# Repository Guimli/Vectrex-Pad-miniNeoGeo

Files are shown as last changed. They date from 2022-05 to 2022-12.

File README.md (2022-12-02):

# Vectrex Pad miniNeoGeo

Allows you to convert a mini NeoGeo controller into a Vectrex controller.

This PCB reuses the analog pad of the mini NeoGeo controller. You will have to unsolder it from the original PCB.
There are two models of the NeoGeo mini controller. One contains classic directional switches (you can hear the clicks when using the directional controller). The other one uses an analogue pad. Make sure you have the right model of controller (the one with the analogue pad) before you start making this Vectrex mod.

!!! Please note that the PCB must be 1.2mm thick !!!

!!! Another warning: It is essential to cut the pins of the two auto-fire switches SW5 and SW6 (OS203011MS1QP1) at the level of the PCB BEFORE soldering. This is because the plastic of the lower part of the joystick has two rings that press on this area. Over soldering in this area could block the auto-fire buttons and deform the plastic at the back.

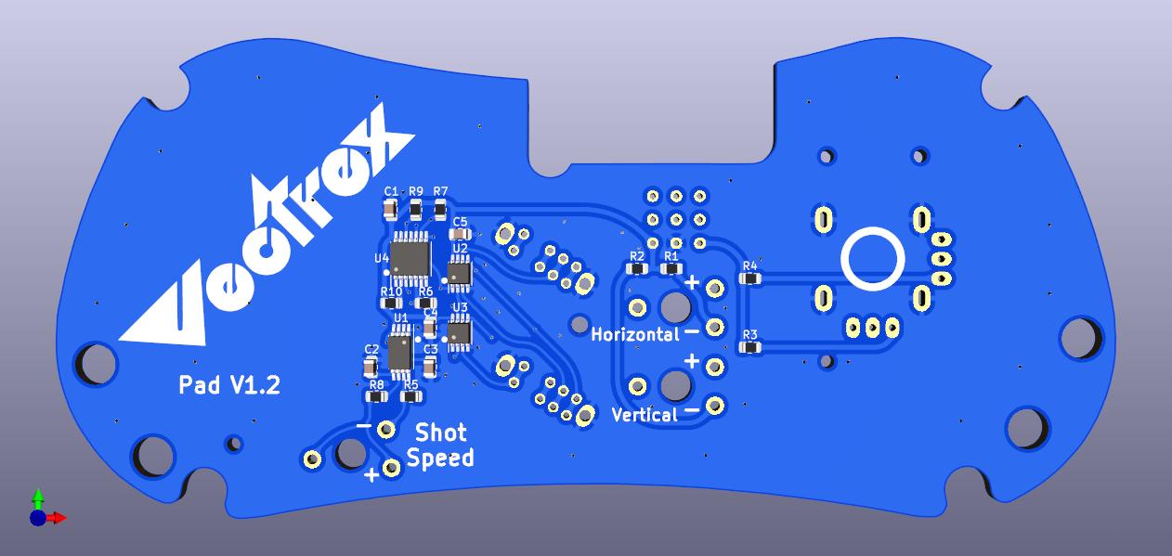
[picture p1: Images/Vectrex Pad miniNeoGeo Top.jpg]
PCB Top


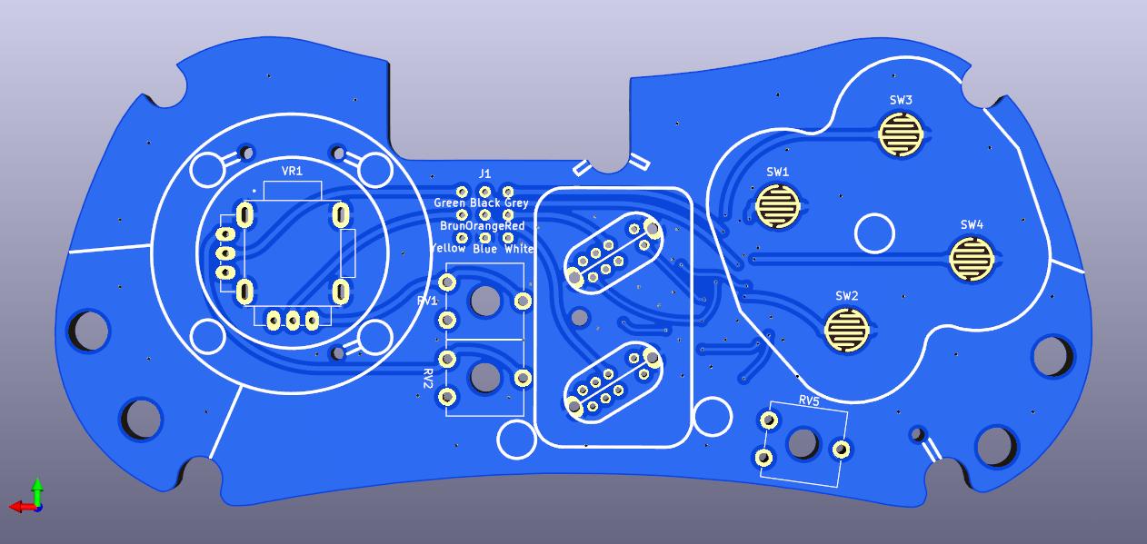
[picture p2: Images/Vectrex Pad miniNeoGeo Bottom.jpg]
PCB Bottom


The Star and Select buttons have been replaced by an auto-fire on the A and D buttons (equivalent to the 1 and 4 button of the Vectrex controller).

## Three possible modes:

> Auto-fire disabled

> Auto-fire when the button is active.

> Auto-fire when the button is inactive (press the button to disables the auto-fire).

The SMD electronics are positioned on one side only to facilitate factory production.

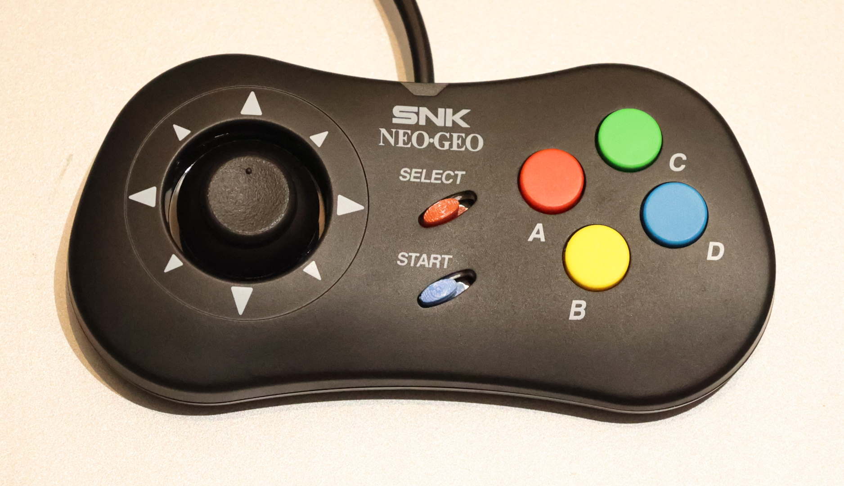
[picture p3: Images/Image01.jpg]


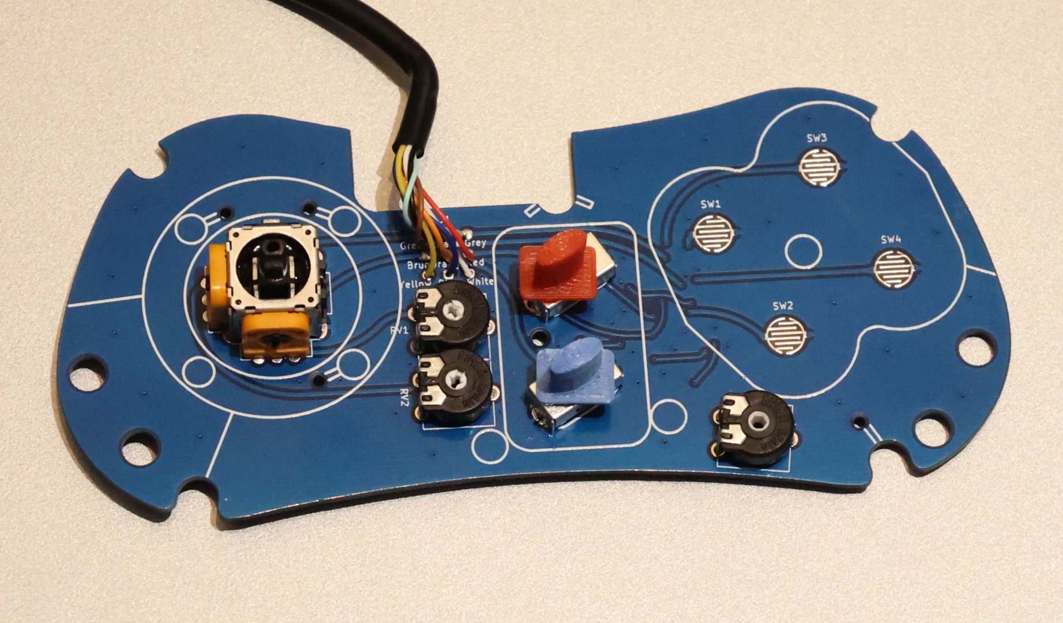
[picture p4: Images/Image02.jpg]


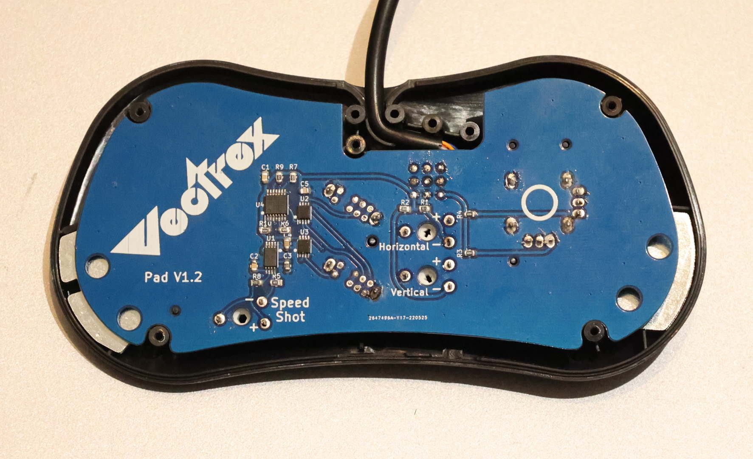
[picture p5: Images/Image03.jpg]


## In the known problems of this controller:
- The auto-fire does not start when the button is pressed. The unstable circuit works continuously. It is therefore possible to have a lag time between the moment the button is pressed and the actual action when the auto-fire is set to low frequency.
- The lack of a user manual (I promise I will try to find the time to do so).

## The strong points of this controller :
- Its low price for a Vectrex controller.
- The very good linearity and amplitude of the analog pad.
- The integrated auto-fire.

## Weaknesses :
- Lack of a knob to adjust the auto-fire speed (adjustment has to be done with a flat screwdriver).

The colour information for the DB9 cable connection on the PCB corresponds to the colours of the cables I bought. This information helps to speed up my own production of controllers. But there is no guarantee that these colours will match the cable you bought. So I'm putting below the correspondence between pin number, function, and the silkscreen inscriptions on my PCB:
- Pin 1 - Button 1 (A) - Red
- Pin 2 - Button 2 (B) - Black
- Pin 3 - Button 3 (C) - Grey
- Pin 4 - Button 4 (D) - Orange
- Pin 5 - Horizontal   - Brun
- Pin 6 - Vertical     - Green
- Pin 7 - +5V          - White
- Pin 8 - GND          - Blue
- Pin 9 - -5V          - Yellow

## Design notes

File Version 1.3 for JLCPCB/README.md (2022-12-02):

# Vectrex Pad miniNeoGeo for JLCPCB PCB Assembly

This version 1.3 has been modified according to the availability of components at JLCPCB for the PCB Assembly. It is likely that by the time you wish to use these Gerbers, the availability has changed.

Version 1.3 also includes a switch to reverse the position of buttons 2 and 3 (B and C).

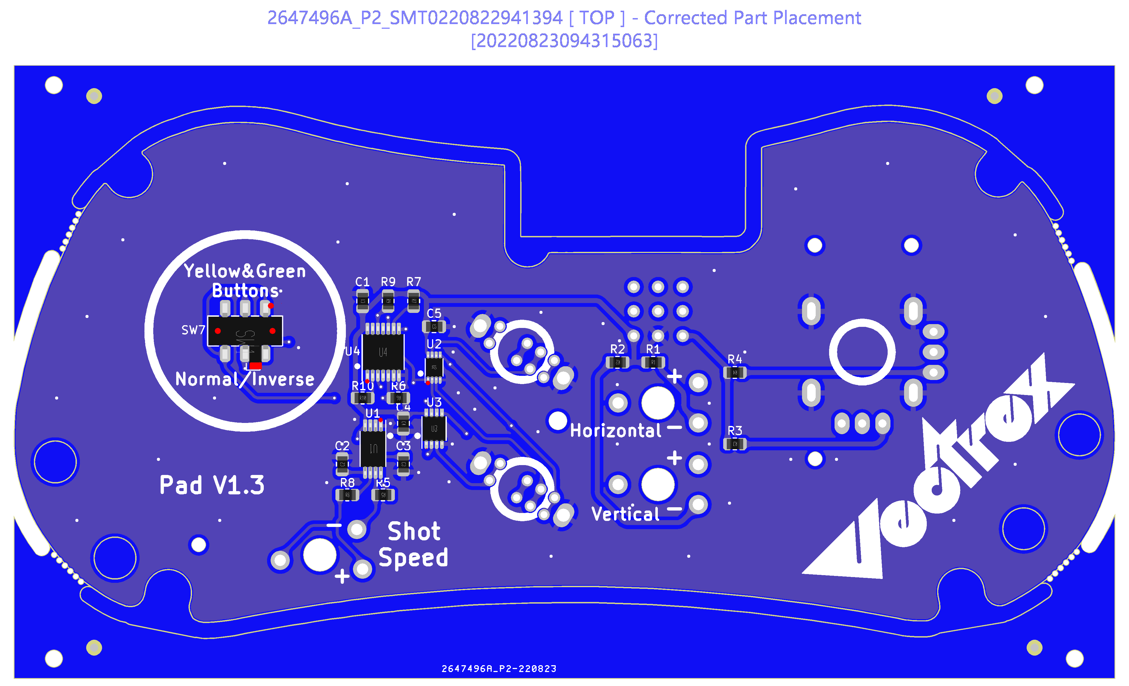
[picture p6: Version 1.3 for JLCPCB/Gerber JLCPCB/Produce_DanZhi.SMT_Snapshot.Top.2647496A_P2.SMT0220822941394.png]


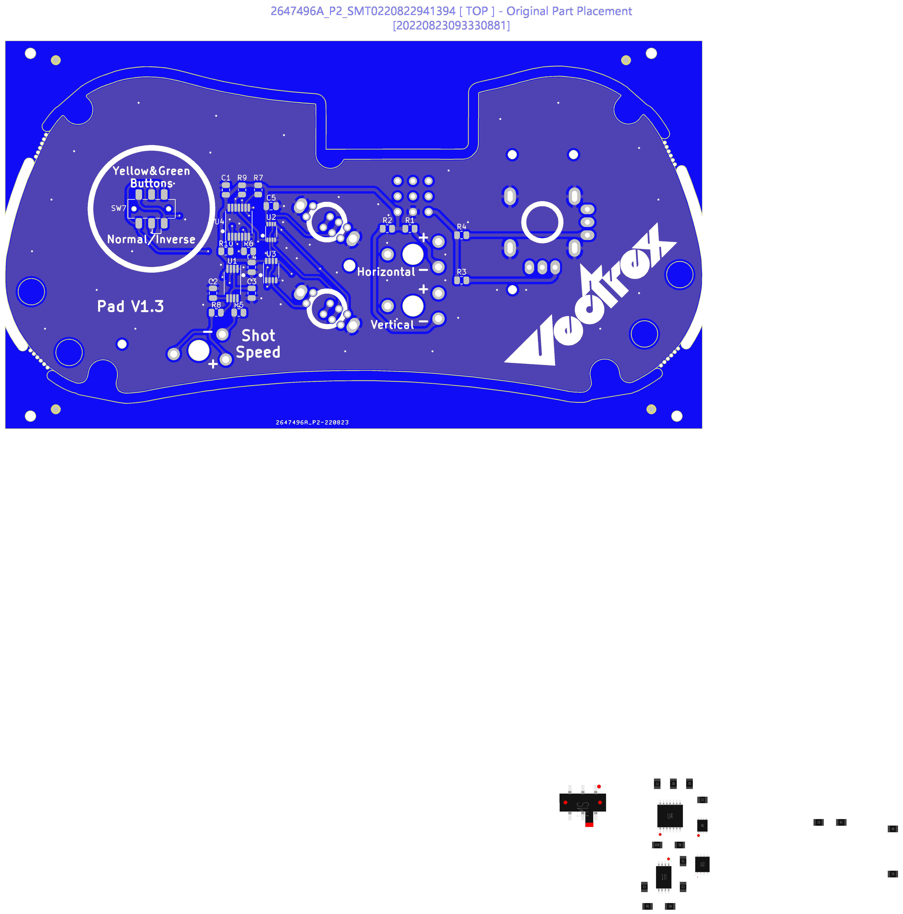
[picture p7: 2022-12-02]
Version 1.3 for JLCPCB/Gerber JLCPCB/Produce_DanZhi.SMT_Original_Snapshot.Top.2647496A_P2.SMT0220822941394.png

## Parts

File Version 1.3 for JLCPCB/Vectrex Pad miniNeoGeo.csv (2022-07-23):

Id | Référence | Boîtier | Quantité | Désignation | Fournisseur et réf
1 | R6,R10,R7,R9 | R_0805_2012Metric | 4 | 470k
2 | C3 | C_0805_2012Metric | 1 | 470nf
3 | U2 | SSOP-8_2.95x2.8mm_P0.65mm | 1 | 74LVC2G32
4 | R8 | R_0805_2012Metric | 1 | 47k
5 | G*** | vectrex-us-silkscreen | 1 | LOGO
6 | R2,R1 | R_0805_2012Metric | 2 | 330
7 | R4,R3 | R_0805_2012Metric | 2 | 820
8 | C2 | C_0805_2012Metric | 1 | 10nF
9 | U4 | TSSOP-14_4.4x5mm_P0.65mm | 1 | 74LS125
10 | U3 | SSOP-8_2.95x2.8mm_P0.65mm | 1 | 74LVC2G00
11 | U1 | TSSOP-8_4.4x3mm_P0.65mm | 1 | NE555D
12 | C4,C5,C1 | C_0805_2012Metric | 3 | 100nF
13 | R5 | R_0805_2012Metric | 1 | 10k
14 | VR1 | F-2116 | 1 | F-2116
15 | RV1,RV2 | Potentiometer_ACP_CA9-V10_Vertical_Hole | 2 | 1k
16 | SW6,SW5 | OS203011MS1QP1 | 2 | SW_DP3T
17 | J1 | DB9 | 1 | DB9_Female
18 | RV5 | Potentiometer_ACP_CA9-V10_Vertical_Hole | 1 | 470k

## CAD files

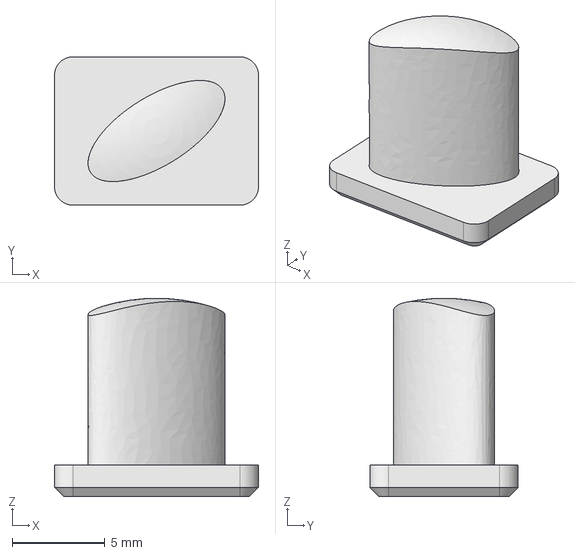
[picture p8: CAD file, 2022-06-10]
Button Blue Auto-Fire.FCStd
11.0 x 8.00 x 10.7 mm

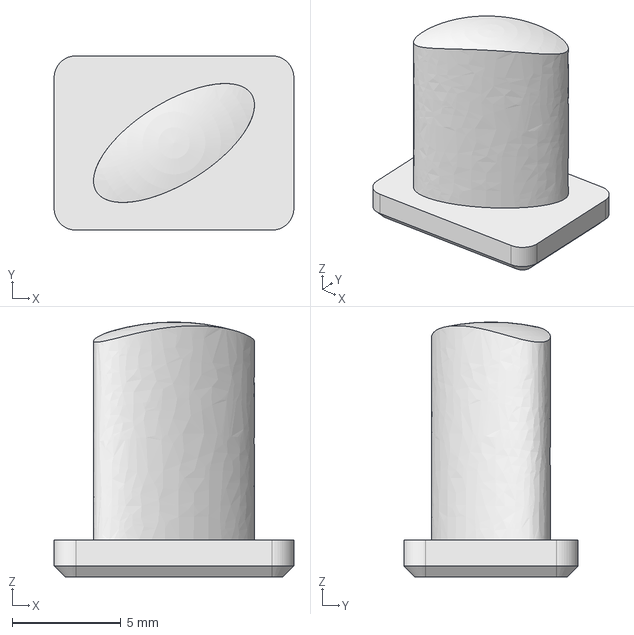
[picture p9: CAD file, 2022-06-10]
Button Red Auto-Fire.FCStd
11.0 x 8.00 x 11.7 mm

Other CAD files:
Button Blue Auto-Fire.stl
Button Red Auto-Fire.stl

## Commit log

2022-04-05 First Release !
    [Vectrex Pad miniNeoGeo-B_Cu.gbr, Vectrex Pad miniNeoGeo-B_Mask.gbr, Vectrex Pad miniNeoGeo-B_Silkscreen.gbr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]
2022-04-20 Production ready
    Complete turn over of the board and passage of all the SMD components on the component side. To allow an assembly in factory.
    [Vectrex Pad miniNeoGeo-B_Cu.gbr, Vectrex Pad miniNeoGeo-B_Mask.gbr, Vectrex Pad miniNeoGeo-B_Silkscreen.gbr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]
2022-04-21 Remove C1 & Cleaning
    Remove C1 (Redundant with C4) and cleaning / optimizing trace & silkscreen
    [Vectrex Pad miniNeoGeo.kicad_sch]
2022-04-27 Round track
    Add Readme.md and PCB with round track.
    [Vectrex Pad miniNeoGeo-B_Cu.gbr, Vectrex Pad miniNeoGeo-B_Mask.gbr, Vectrex Pad miniNeoGeo-B_Silkscreen.gbr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]
2022-04-27 Correct a track
    Just a little optimization
    [Vectrex Pad miniNeoGeo-rounded-B_Cu.gbr, Vectrex Pad miniNeoGeo-rounded-B_Mask.gbr, Vectrex Pad miniNeoGeo-rounded-B_Silkscreen.gbr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]
2022-05-01 Replace 1k resistor with 470
    The value of the resistors for the sensitivity of the analog pad is too high. Test with 470 ohms.
    [Vectrex Pad miniNeoGeo-B_Cu.gbr, Vectrex Pad miniNeoGeo-B_Mask.gbr, Vectrex Pad miniNeoGeo-B_Silkscreen.gbr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]
2022-05-12 Correct issue #1
    Because of the resistance of the silicone contacts, it is necessary to press hard on the buttons to make the contact.
    [Vectrex Pad miniNeoGeo-B_Cu.gbr, Vectrex Pad miniNeoGeo-B_Mask.gbr, Vectrex Pad miniNeoGeo-B_Silkscreen.gbr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]
2022-05-24 Suppression of redundant potentiometers
    [Vectrex Pad miniNeoGeo-B_Cu.gbr, Vectrex Pad miniNeoGeo-B_Mask.gbr, Vectrex Pad miniNeoGeo-B_Silkscreen.gbr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]
2022-05-26 Rotate R3 & R4 label
    Rotate R3 & R4 label
    Replace Speed Shot by Shot Speed
    [Vectrex Pad miniNeoGeo-B_Cu.gbr, Vectrex Pad miniNeoGeo-B_Mask.gbr, Vectrex Pad miniNeoGeo-B_Silkscreen.gbr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]
2022-05-28 Add auto-fire button 3D printing
    [Button Auto-Fire.FCStd, Button Auto-Fire.stl]
2022-05-29 Reduce Custody
    [Button Auto-Fire.FCStd, Button Auto-Fire.stl]
2022-06-10 3D Button of different size and color
    3D Button of different size and color
    Minor update
    [Button Auto-Fire.FCStd, Button Auto-Fire.stl, Button Blue Auto-Fire.FCStd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]
2022-06-10 Correct bad shape attachement
    [Button Blue Auto-Fire.FCStd, Button Blue Auto-Fire.stl, Button Red Auto-Fire.FCStd]
2022-07-07 Folder for Gerber files
    Folder for Gerber files. For more readability in the root folder.
    [Vectrex Pad miniNeoGeo-B_Cu.gbr, Vectrex Pad miniNeoGeo-B_Mask.gbr, Vectrex Pad miniNeoGeo-B_Silkscreen.gbr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]
2022-07-12 Warning for the 1.2mm thickness of the PCB
2022-07-14 Add gerber zip
2022-07-23 Invert NAND et OR gate
    It makes more sense for auto-auto-fire to be in the extreme position. To avoid generating an unwanted press while moving the switch.
    [Vectrex Pad miniNeoGeo.csv, Vectrex Pad miniNeoGeo.kicad_sch]
2022-12-02 Add JLCPCB PCB Assembly version
    [BOM_Vectrex Pad miniNeoGeo_2022-08-21.xls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]
